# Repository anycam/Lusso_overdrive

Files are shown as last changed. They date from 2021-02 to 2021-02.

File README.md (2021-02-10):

# Lusso Overdrive
###### Get a crunch and boost !

This guitar pedal is based on the Klon centaur and the well knwon green friend TS, adding a 2 band EQ for low pass and high pass filtering along with a two modes bypass using two relays and an PIC uC programmed in C++.

Feel free to make your own pedal, here you can find the schematic, pcb and gerber files ready to send into your favorite pcb manufacturer.

## Gallery 

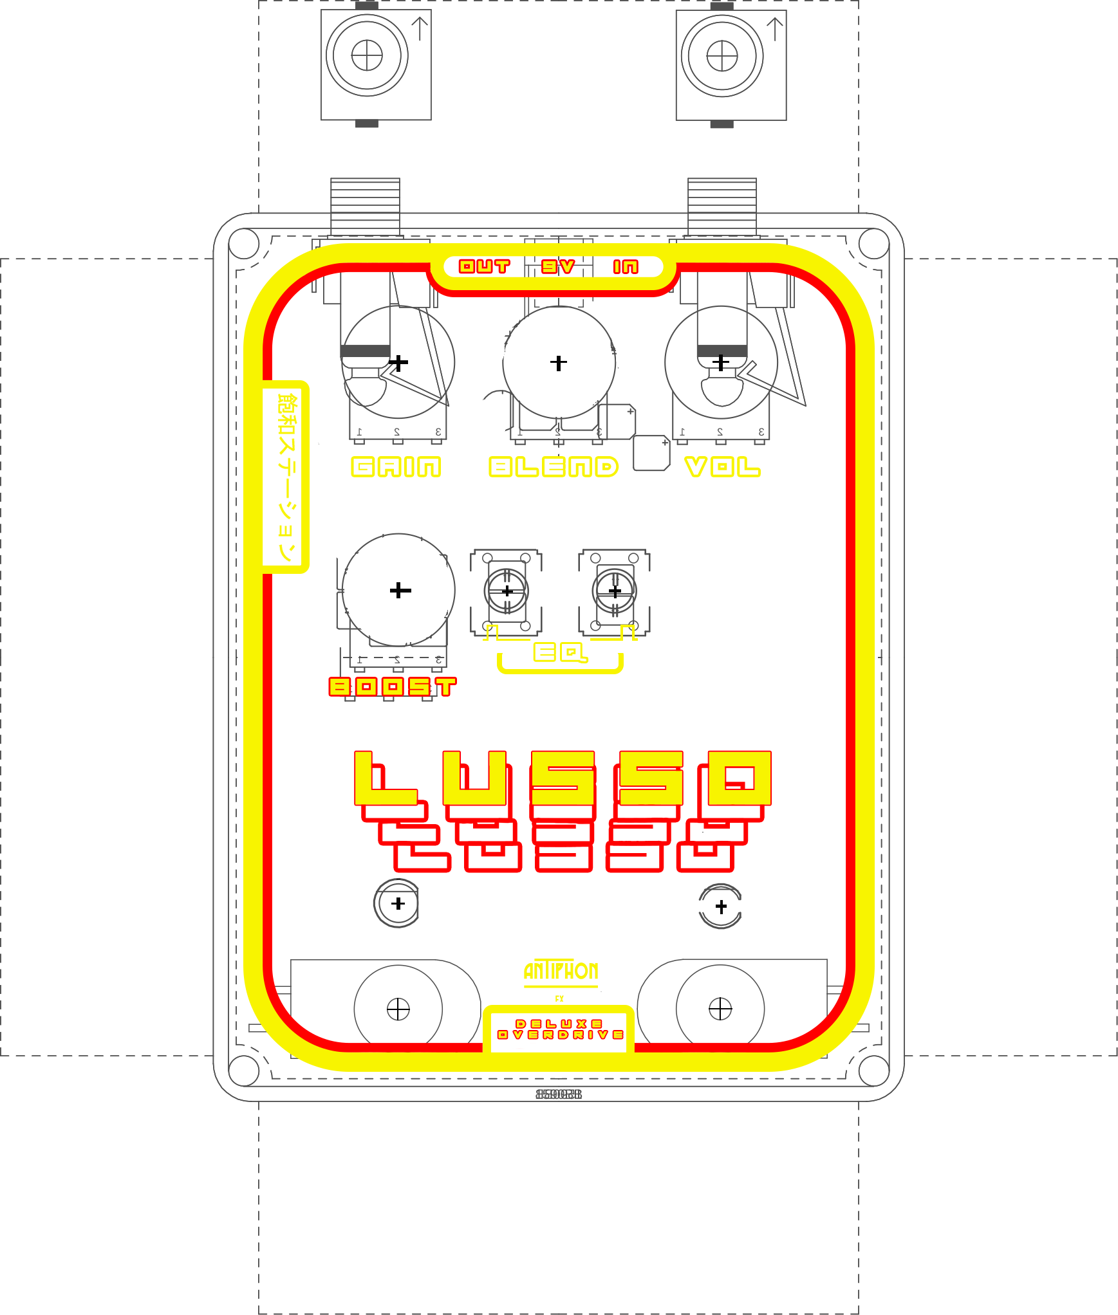
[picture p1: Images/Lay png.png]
Lusso


PCB

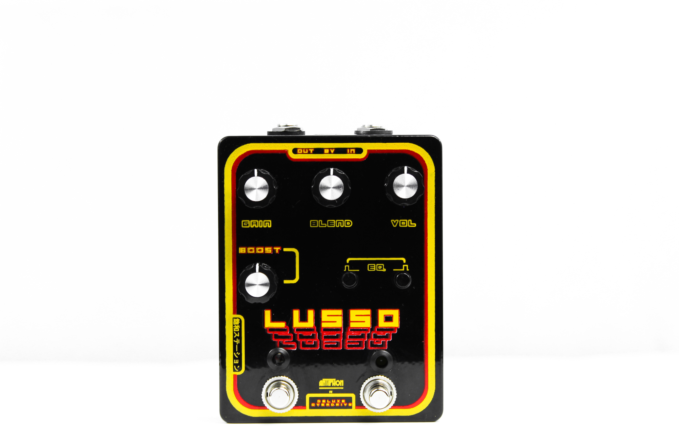
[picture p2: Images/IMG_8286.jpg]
Front


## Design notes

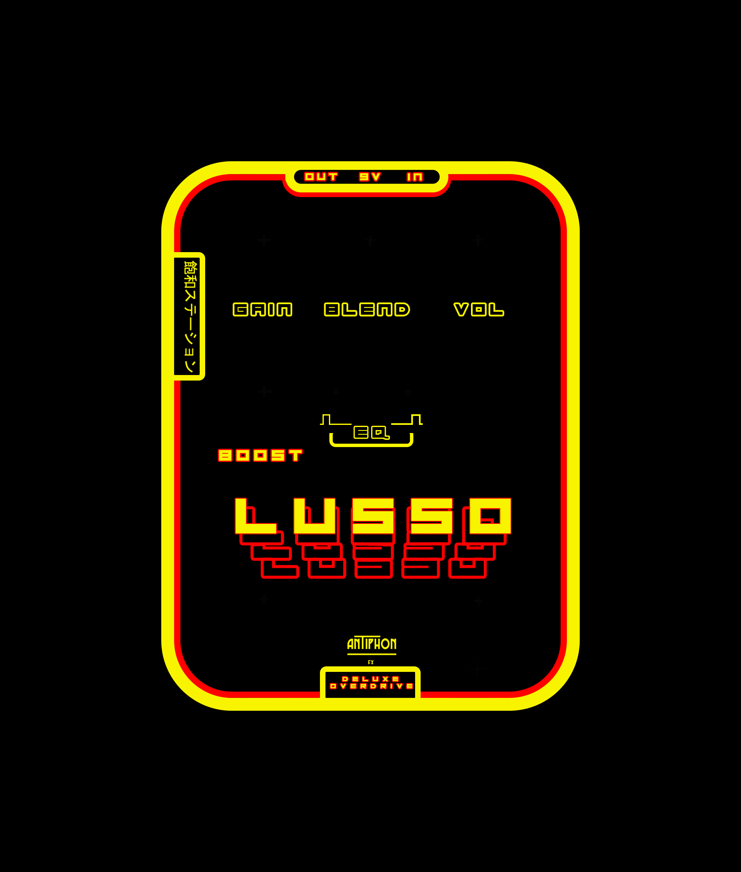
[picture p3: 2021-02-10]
Images/LayBlack.jpg

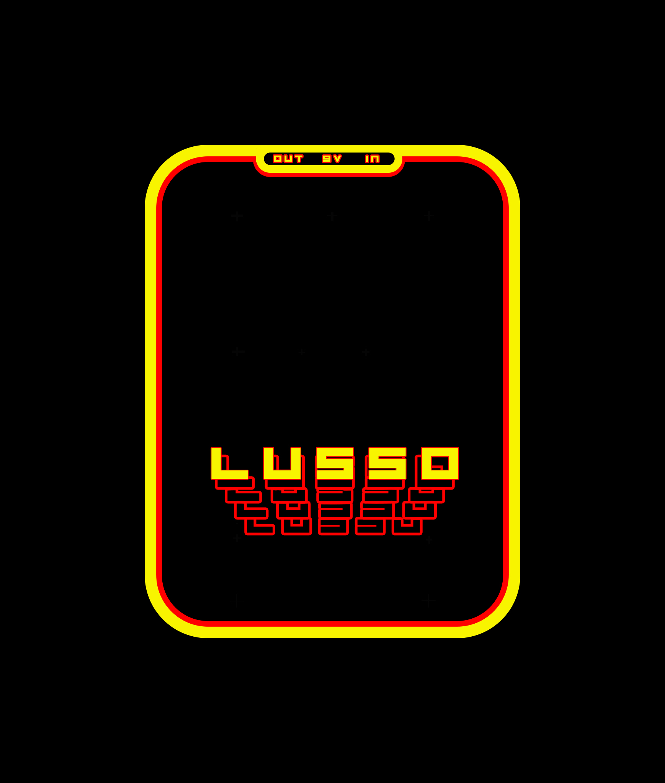
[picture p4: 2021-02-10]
Images/LayNew.jpg

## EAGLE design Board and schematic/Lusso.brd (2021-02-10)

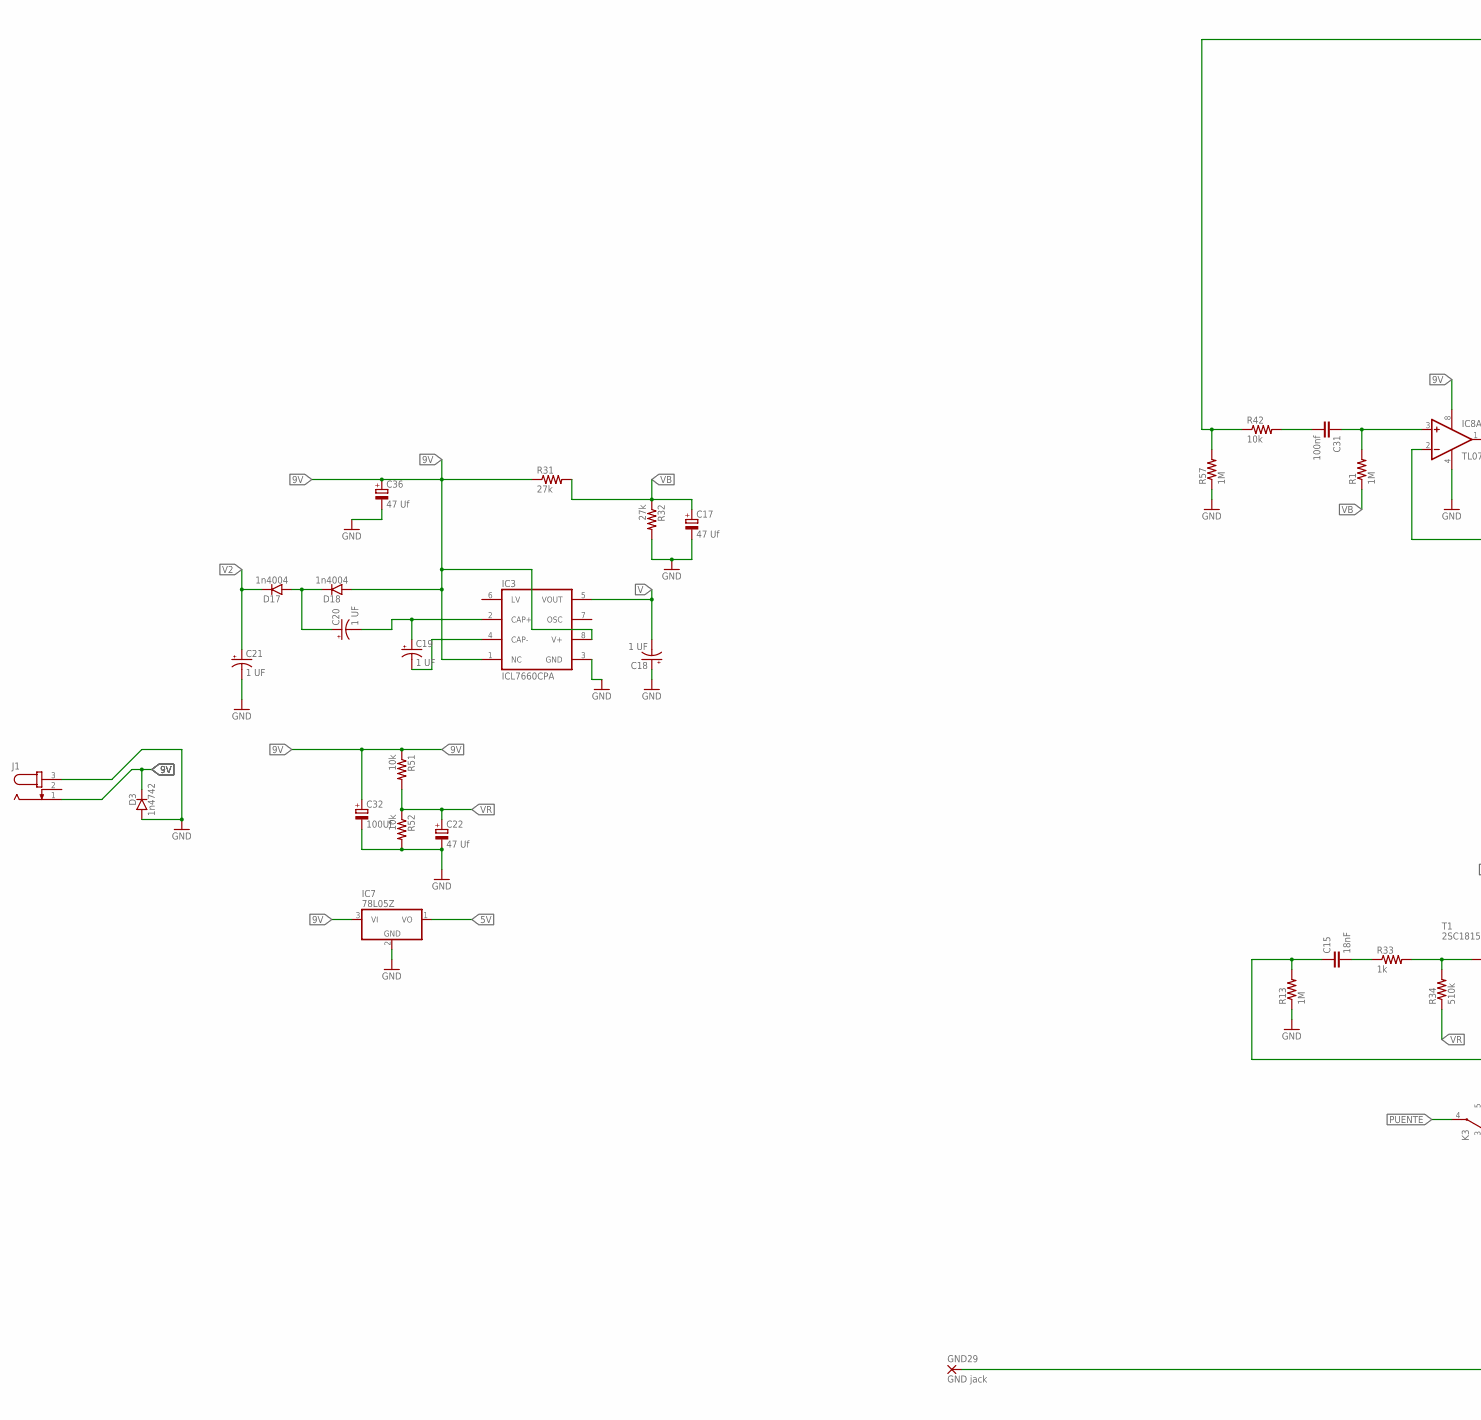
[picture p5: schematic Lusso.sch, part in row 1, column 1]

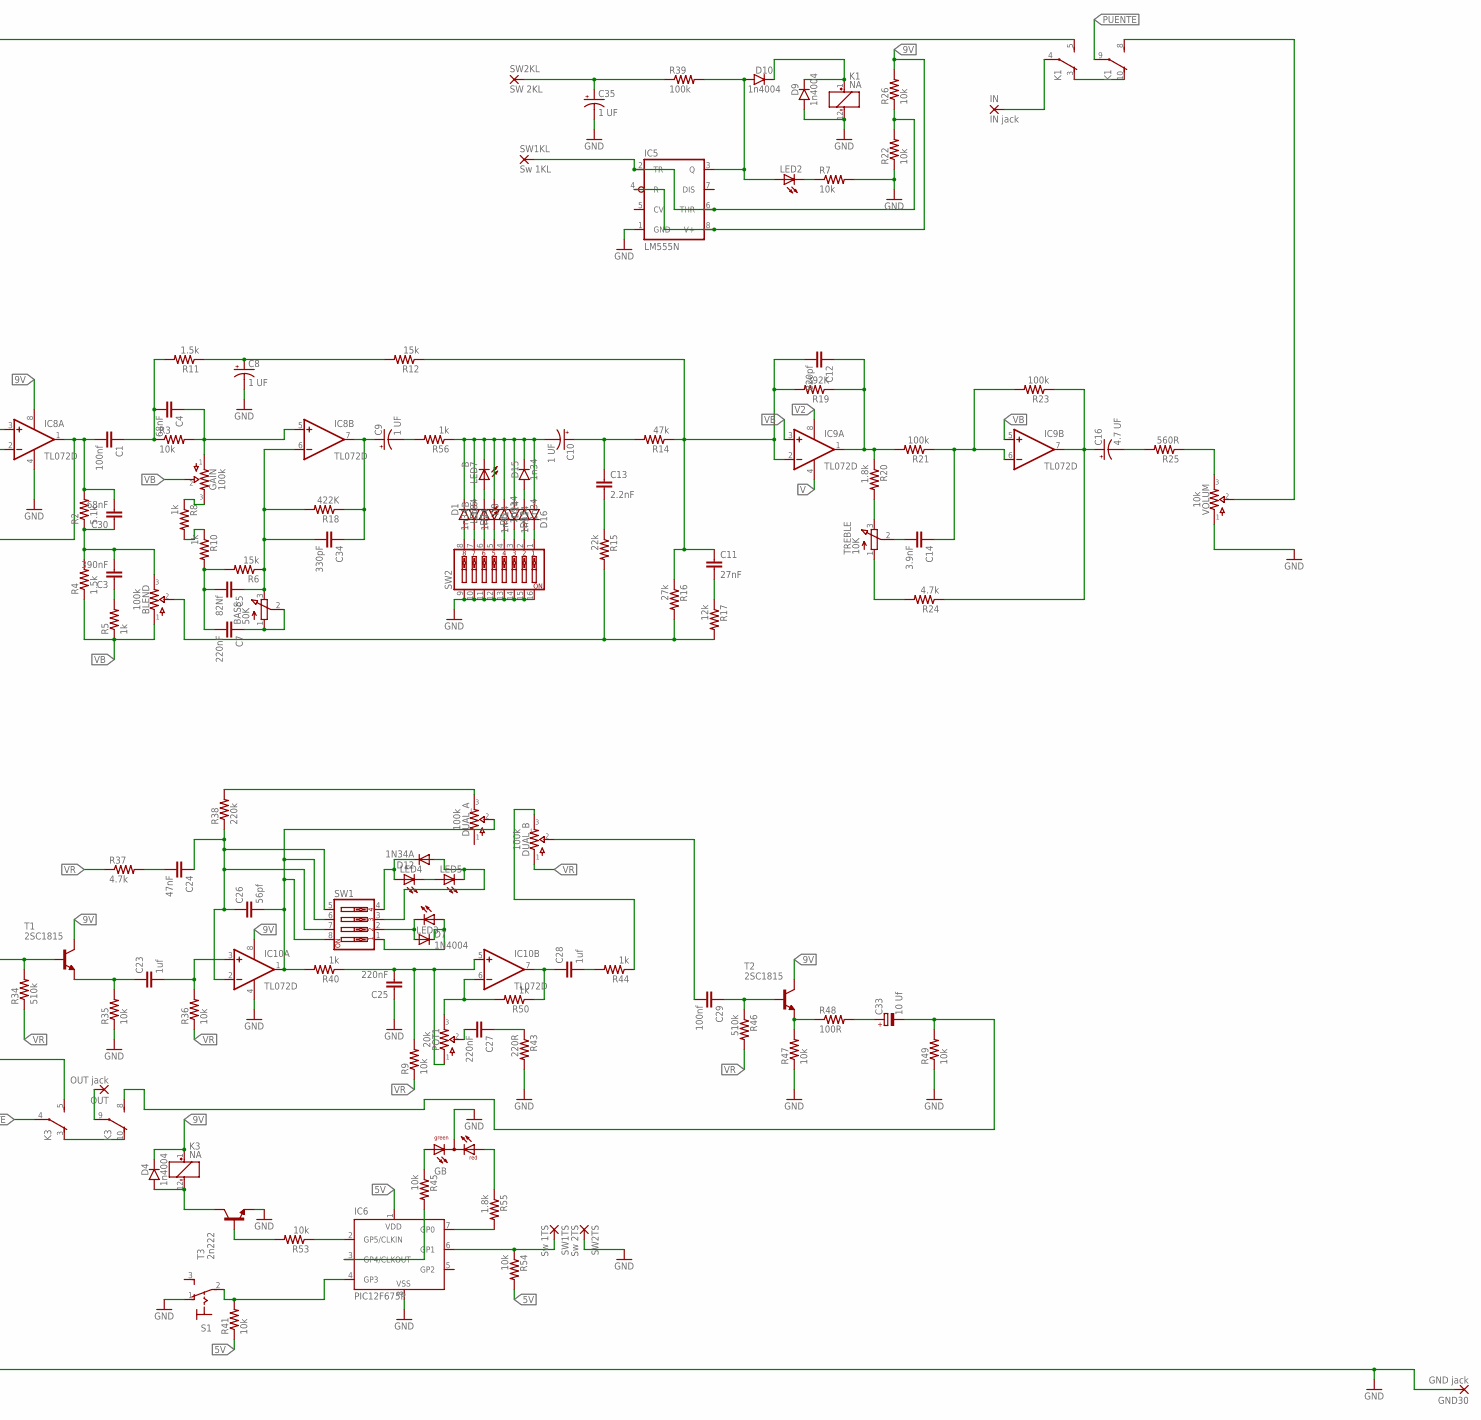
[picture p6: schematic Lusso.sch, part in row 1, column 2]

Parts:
BASS: 50K; EVUF
BLEND: 100k; 16MM_B.MOUNT
C1, C29, C31: 100nf; C0805
C3: 390nF; C2.5-3
C4, C30: 68nF; C0805
C5: 82Nf; C2.5-3
C7, C25, C27: 220nF; C0805
C8, C9, C10, C18, C19, C20, C21, C35: 1 UF; B45181A
C11: 27nF; C2.5-3
C12: 820pf; C0805
C13: 2.2nF; C2.5-3
C14: 3.9nF; C0805
C15: 18nF; C2.5-3
C16: 4.7 UF; B45181A
C17, C22, C36: 47 Uf; PANASONIC_B
C23, C28: 1uf; C1206
C24: 47nF; C0805
C26: 56pf; C0805
C32: 100Uf; PANASONIC_B
C33: 10 Uf; PANASONIC_B
C34: 330pF; C0805
D1, D2, D5, D14, D15: 1n34; DO35-3
D3: 1n4742; DO35-3
D4, D9, D10, D17, D18: 1n4004; DO35-3
D7: 1N4004; DO41-10
D8, D13, D16: 1n914; DO35-3
D12: 1N34A; DO41-10
DUAL: 100k; 16MM_DUALGANG
GAIN: 100k; 16MM_B.MOUNT
GB: DUOLED-RG-C; DUOLED-C-5MM
GND29, GND30: GND jack; 2,15/1,0
IC3: ICL7660CPA; DIL08
IC5: LM555N; DIL08
IC6: PIC12F675P; DIL8
IC7: 78L05Z; TO92
IC8, IC9, IC10: TL072D; SO08
IN: IN jack; 2,15/1,0
J1: JACK-PLUG0; SPC4077
K1, K3: NA
LED2, LED3, LED4, LED5: LED5MM
LED6, LED7: B; LED5MM
OUT: OUT jack; 2,15/1,0
POT1: 20k; TRIM1
R1, R13, R57: 1M; R1206
R2: 5.1k; M0805
R3, R7, R9, R22, R26, R35, R36, R41, R42, R45, R47, R49, R51, R52, R53, R54: 10k; M0805
R4, R11: 1.5k; M0805
R5, R8, R10, R33, R40, R44, R50, R56: 1k; M0805
R6, R12: 15k; M0805
R14: 47k; M0805
R15: 22k; M0805
R16, R31, R32: 27k; M0805
R17: 12k; M0805
R18: 422K; 0204/7
R19: 392K; 0204/7
R20, R55: 1.8k; M0805
R21, R23, R39: 100k; M0805
R24, R37: 4.7k; M0805
R25: 560R; M0805
R34, R46: 510k; M0805
R38: 220k; M0805
R43: 220R; M0805
R48: 100R; M0805
S1: 320-916
SW1: SW_DIP-4; EDG-04
SW1KL: Sw 1KL; 2,15/1,0
SW1TS: Sw 1TS; 2,15/1,0
SW2: SW_DIP-8; EDG-08
SW2KL: SW 2KL; 2,15/1,0
SW2TS: Sw 2TS; 2,15/1,0
T1, T2: 2SC1815; TO92-ECB
T3: 2n222; TO18
TREBLE: 10K; EVUF
VOLUM: 10k; 16MM_B.MOUNT

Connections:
5V: IC6.1 (VDD), IC7.1 (VO), R41.1, R54.2
9V: C32.+, C36.+, D3.C, D4.C, D18.A, IC3.1 (NC), IC3.8 (V+), IC5.4 (R), IC5.8 (V+), IC7.3 (VI), IC8.8 (V+), IC10.8 (V+), J1.1, K3.1 (+), R26.2, R31.1, R51.1, T1.C, T2.C
GND: C8.-, C17.-, C18.+, C21.-, C22.-, C25.1, C32.-, C35.-, C36.-, D3.A, D9.A, GB.C, GND29.1, GND30.1, IC3.3 (GND), IC5.1 (GND), IC6.8 (VSS), IC7.2 (GND), IC8.4 (V-), IC10.4 (V-), J1.3, K1.12 (-), R7.2, R13.1, R22.1, R32.2, R35.1, R43.2, R47.1, R49.1, R52.2, R57.1, S1.1 (O), SW2.9, SW2.10, SW2.11, SW2.12, SW2.13, SW2.14, SW2.15, SW2.16, SW2TS.1, T3.1 (E), VOLUM.1
unnamed: C31.2, R42.2
unnamed: C31.1, IC8.3 (+IN), R1.2
unnamed: C1.2, C30.2, IC8.1 (OUT), IC8.2 (-IN), R2.2
unnamed: BLEND.3, C3.2, C30.1, R2.1, R4.2
unnamed: BASS.1 (A), BASS.2 (S), C7.1
unnamed: C3.1, R5.2
unnamed: C1.1, C4.2, R3.1, R11.2
unnamed: C4.1, GAIN.1, IC8.5 (+IN), R3.2
unnamed: GAIN.3, R8.1
unnamed: C5.2, C7.2, R6.2, R10.2
unnamed: BASS.3 (E), C5.1, C34.2, IC8.6 (-IN), R6.1, R18.2
unnamed: C12.1, IC9.1 (OUT), R19.1, R20.1, R21.2
unnamed: K3.3 (O), K3.10 (O)
unnamed: C8.+, R11.1, R12.2
unnamed: R20.2, TREBLE.3 (E)
unnamed: C9.+, C34.1, IC8.7 (OUT), R18.1
unnamed: C9.-, R56.2
unnamed: C10.-, D1.C, D2.A, D5.A, D8.C, D13.A, D15.C, D16.A, LED7.K (C), R56.1
unnamed: C14.2, TREBLE.2 (S)
unnamed: C10.+, C13.1, R14.2
unnamed: C13.2, R15.1
unnamed: C11.2, R17.1
unnamed: C11.1, C12.2, IC9.2 (-IN), R12.1, R14.1, R16.1, R19.2
unnamed: BLEND.2, R15.2, R16.2, R17.2
unnamed: C14.1, IC9.6 (-IN), R21.1, R23.2
unnamed: C16.+, IC9.7 (OUT), R23.1, R24.1
unnamed: C16.-, R25.2
unnamed: R25.1, VOLUM.3
unnamed: K1.3 (O), K1.10 (O)
unnamed: R8.2, R10.1
unnamed: K1.8 (S), VOLUM.2
unnamed: R24.2, TREBLE.1 (A)
unnamed: DUAL.3, R38.2
unnamed: DUAL.6 (3), R44.1
unnamed: C15.2, R33.1
unnamed: C20.+, D17.A, D18.C
unnamed: C29.2, DUAL.5 (2)
unnamed: C19.+, C20.-, IC3.2 (CAP+)
unnamed: IC5.2 (TR), IC5.6 (THR), R22.2, R26.1, SW1KL.1
unnamed: LED2.K (C), R7.1
unnamed: IC6.4 (GP3), R41.2, S1.2
unnamed: C35.+, R39.1, SW2KL.1
unnamed: D10.A, IC5.3 (Q), LED2.A, R39.2
unnamed: D9.C, D10.C, K1.1 (+)
unnamed: IC6.2 (GP5/CLKIN), R53.1
unnamed: D1.A, SW2.8
unnamed: R33.2, R34.2, T1.B
unnamed: R53.2, T3.2 (B)
unnamed: D4.A, K3.12 (-), T3.3 (C)
unnamed: C23.1, R35.2, T1.E
unnamed: D2.C, SW2.7
unnamed: IC6.3 (GP4/CLKOUT), R45.2
unnamed: C24.1, C26.1, IC10.2 (-IN), R38.1, SW1.5, SW1.7
unnamed: C26.2, DUAL.2, IC10.1 (OUT), R40.2, SW1.6, SW1.8
unnamed: IC6.6 (GP1), R54.1, SW1TS.1
unnamed: C24.2, R37.2
unnamed: IC6.7 (GP0), R55.2
unnamed: C25.2, IC10.5 (+IN), POT1.1, R9.2, R40.1
unnamed: GB.AX (AG), R45.1
unnamed: IC10.6 (-IN), POT1.3, R50.2
unnamed: C27.2, POT1.2
unnamed: C27.1, R43.1
unnamed: C28.1, IC10.7 (OUT), R50.1
unnamed: C28.2, R44.2
unnamed: GB.AR, R55.1
unnamed: D12.C, LED4.A, SW1.4
unnamed: C29.1, R46.1, T2.B
unnamed: R47.2, R48.1, T2.E
unnamed: LED4.K (C), LED5.A
unnamed: C33.+, R48.2
unnamed: C33.-, K3.8 (S), R49.2
unnamed: D12.A, LED5.K (C), SW1.3
unnamed: D7.A, LED3.K (C), SW1.2
unnamed: D7.C, LED3.A, SW1.1
unnamed: LED6.A, SW2.6
unnamed: LED6.K (C), LED7.A
unnamed: C23.2, IC10.3 (+IN), R36.2
unnamed: D5.C, SW2.5
unnamed: D8.A, SW2.4
unnamed: C19.-, IC3.4 (CAP-)
unnamed: D13.C, SW2.3
unnamed: D14.C, D15.A
unnamed: D14.A, SW2.2
unnamed: D16.C, SW2.1
unnamed: C15.1, K3.5 (S), R13.2
unnamed: K1.5 (S), R42.1, R57.2
unnamed: IN.1, K1.4
unnamed: K3.9, OUT.1
PUENTE: K1.9, K3.4
V: C18.-, IC3.5 (VOUT), IC9.4 (V-)
V2: C21.+, D17.C, IC9.8 (V+)
VB: BLEND.1, C17.+, GAIN.2, IC9.3 (+IN), IC9.5 (+IN), R1.1, R4.1, R5.1, R31.2, R32.1
VR: C22.+, DUAL.4 (1), R9.1, R34.1, R36.1, R37.1, R46.2, R51.2, R52.1

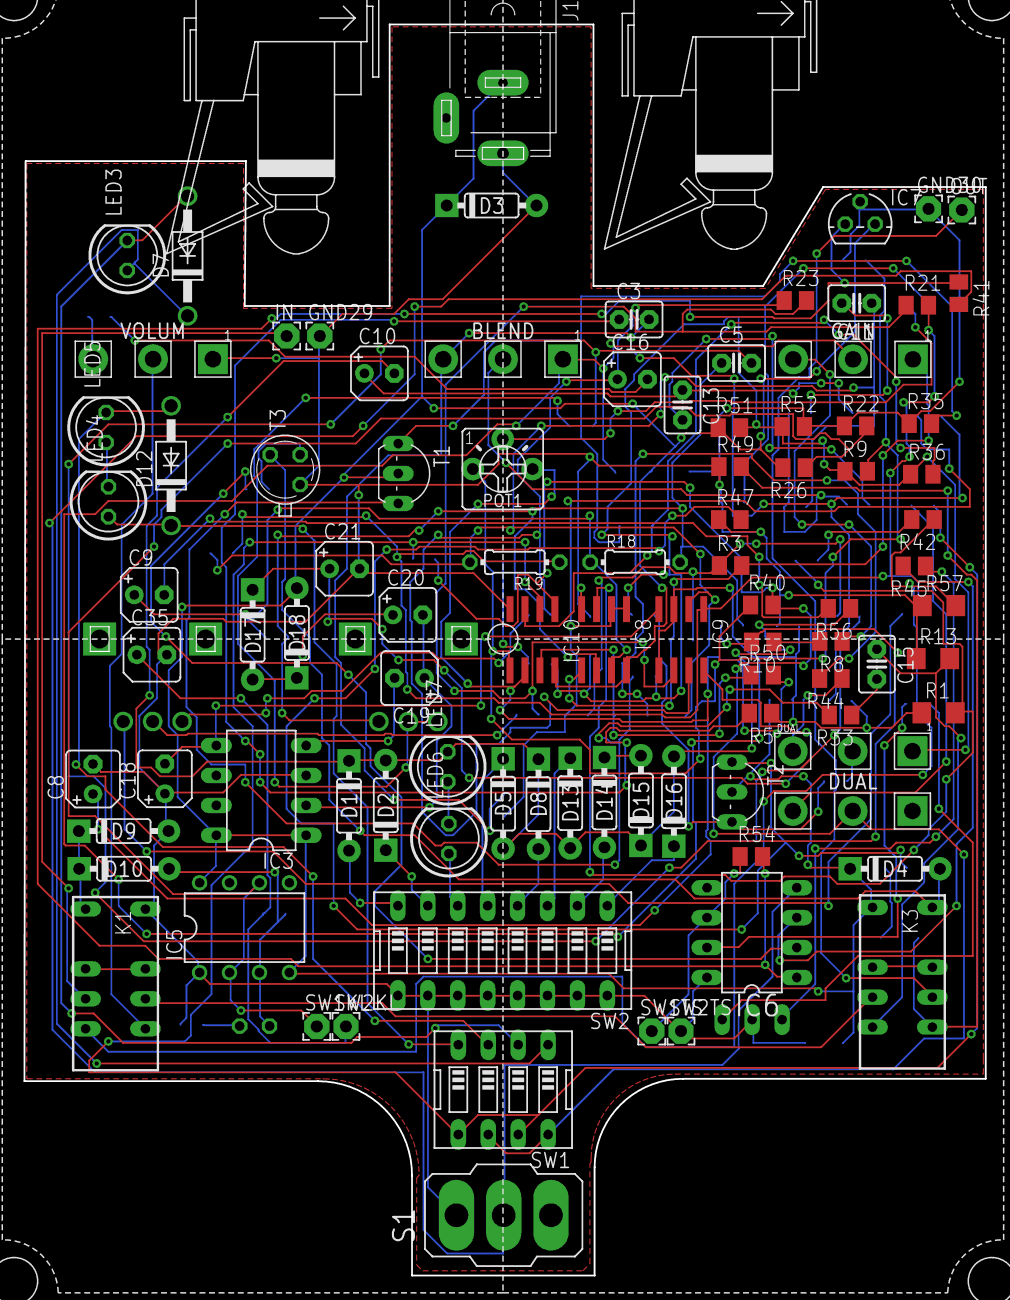
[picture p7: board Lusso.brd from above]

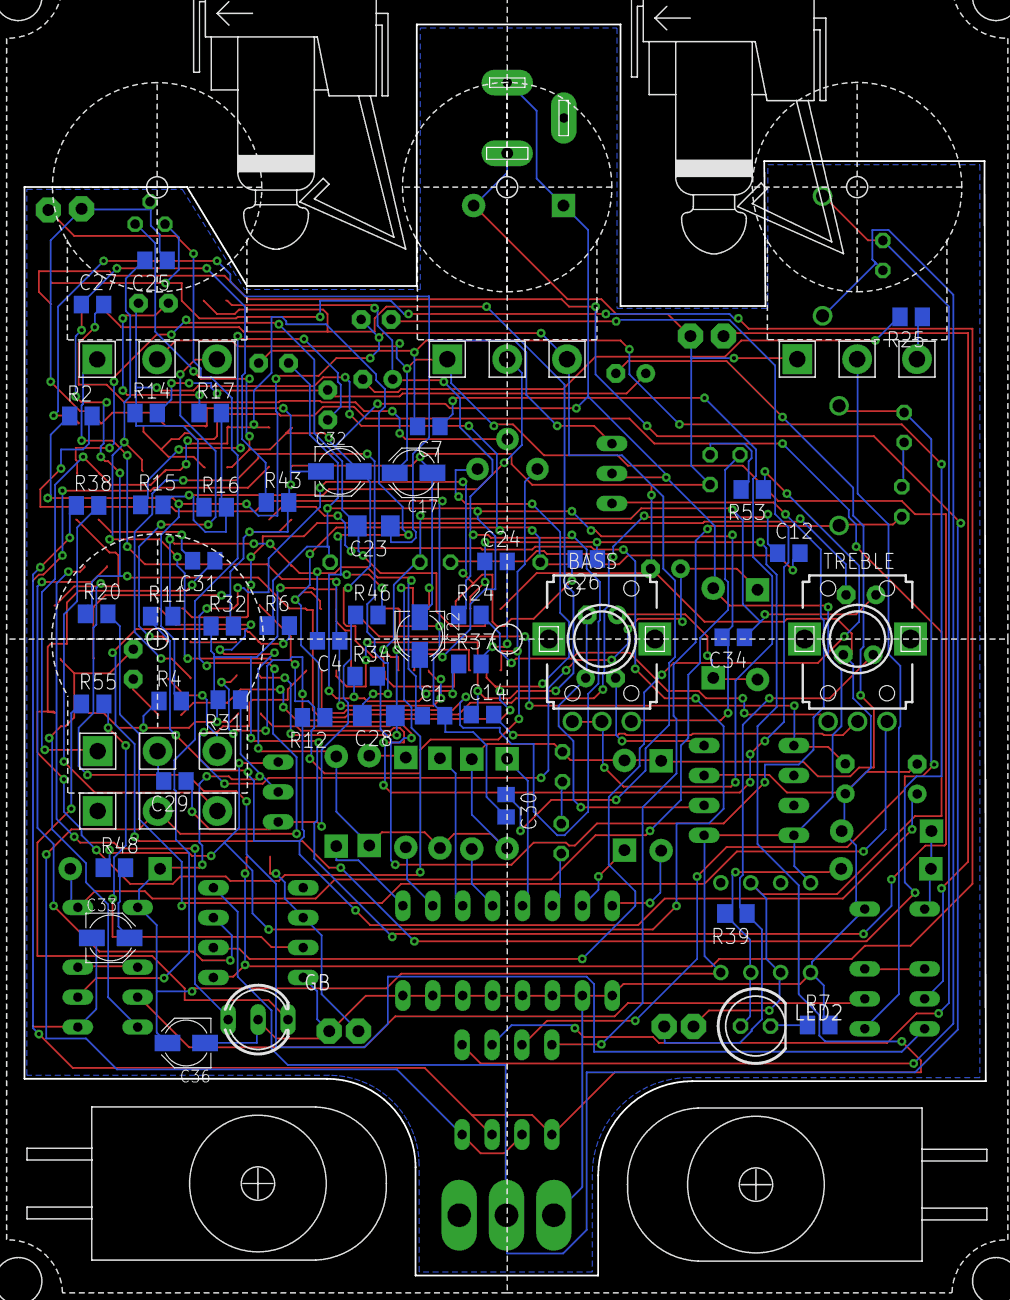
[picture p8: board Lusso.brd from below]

Board: 2 copper layers, 81.6 x 106.2 mm, 146 parts (48 on the bottom side), 96 nets.

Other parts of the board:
U$1: 1590BB
U$2, U$3: LUMBURG_SIDE
U$4, U$5: MOMENTARY
